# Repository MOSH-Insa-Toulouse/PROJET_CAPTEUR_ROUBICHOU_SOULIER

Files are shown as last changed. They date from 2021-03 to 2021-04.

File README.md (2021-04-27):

# Projet Capteur Graphite ROUBICHOU SOULIER
Bienvenue sur notre Github, découvrez notre travail !

# Sommaire
<!-- TOC depthFrom:2 -->
  - [1. Description](#1-description)
  - [2. Arduino](#2-arduino)
     - [2.1. Bibliothèques](#22-bibliothèques)
     - [2.2. Notre code Arduino](#22-notre-code-arduino)
  - [3. KICAD](#3-kicad)
  - [4. Application Android](#4-application-android)
     - [4.1. MIT App Inventor](#41-mit-app-inventor)
     - [4.2. Installer une application](#42-installer-une-application)
     - [4.3. Notre application](#43-notre-application)
  - [5. Bancs de test](#5-bancs-de-test)
     - [5.1. Première version](#51-première-version)
     - [5.2. Seconde version](#52-seconde-version)
     - [5.3. Résultats](#53-résultats)
  - [6. Améliorations possibles](#6-améliorations-possibles)
  - [7. Informations sur les auteurs](#7-informations-sur-les-auteurs)
<!-- /TOC -->

## 1. Description

Ce Git contient toutes les ressources nécessaires pour le projet capteur 2021 du Génie Physique de l'INSA de Toulouse. Ce projet à pour but le développement d'un **capteur de déformation** à bas coût et écoresponsable. Notre capteur exploite la dépendance entre la conductivité électrique et l’espace moyen entre les particules au sein d’un système granuleux. Le transport des électrons entre les nanoparticules de graphite est régi par l’effet tunnel. Ainsi, l’extension et la contraction du réseau percolé induit par un stress mécanique affectent la distance inter-particule et donc la conductivité électrique globale de la couche de graphite. L’écriture au crayon sur du papier permet la mise en place d’une couche de graphite présentant un réseau percolé. Sa déformation provoque une variation de résistance réversible et exploitable pour créer un extensomètre. Le conditionneur de notre capteur est un Shield comportant un circuit transimpédence ainsi que des interfaces pour un module bluetooth, une roue codeuse et un écran OLED. Ce dernier à été réalisé sur **KICAD**. Le code principal à été réalisé en C++ sur l'**IDE Arduino**. Un application téléphone à été développée sur **MIT App Inventor** pour communiquer et recevoir des données à distance, mais aussi pour contrôler les paramètres du capteur. Un banc de mesure réalisé en **impression 3D** nous permet à l'aide d'un servomoteur d'étudier la réponse en déformation de différents capteurs (dont la concentration en graphite varie).

**Code Arduino**

- Mesure la tension de sortie du circuit transimpédance
- Envoie la mesure de la tension en Bluetooth sur 1 octet
- Calcule la résistance du capteur de graphite connaissant la fonction de transfert du conditionneur
- Affiche les mesures de tension, de résistance et la fréquence d'acquisition choisie sur un écran oled 128x64
- Gère l'encodeur rotatoire pour changer la fréquence d'acquisition

**KICAD**

- PCB sous forme de Shield pour carte Arduino UNO
- Interface du capteur graphite via un circuit transimpédance
- Interface un module Bluetooth
- Interface un écran oled
- Interface un encodeur rotatoire

**Application**

- Récupère la mesure de tension
- Calcule la résistance du capteur de graphite connaissant la fonction de transfert du conditionneur
- Affiche la valeur de la résistance en MΩ
- Trace un graphique qui décrit l'évolution de la mesure de tension au cours du temps
- Mise à l'échelle automatique de l'ordonnée du graphique
- Possibilité de changer la fréquence d'acquisition (100 ou 20 Hz)
- Possibilité de mettre sur ON ou OFF l'application en temps réel

**Banc de test**

- Fonctionne avec un servomoteur
- Permet de générer des contraintes avec des consignes d'angles
- Permet une grande plage de contraintes
- Améliore la répétabilité des mesures
- Permet la mise en place de mesures autonomes
- Limite la déterioration des capteurs de graphite

## 2. Arduino

_Comment installer l'IDE Arduino sur sa machine? Vous trouverez la réponse [ici](https://www.arduino.cc/en/software)_

### 2.1 Bibliothèques

- Installez la bibliothèque "Adafruit GFX Library" [ici](https://github.com/adafruit/Adafruit-GFX-Library)
- Installez la bibliothèque "Adafruit SSD1306" [ici](https://github.com/adafruit/Adafruit_SSD1306)
- Installez la bibliothèque "Adafruit BusIOa" [ici](https://github.com/adafruit/Adafruit_BusIO)

_Comment installer une bibliothèque Arduino? Vous trouverez la réponse [ici](https://www.arduino.cc/en/Guide/Libraries#how-to-install-a-library)_

### 2.2. Notre code Arduino

Le code que nous avons développé permet de:
- Mesurer la tension de sortie du circuit transimpédance
- Envoyer la mesure de la tension en Bluetooth sur 1 octet
- Calculer la résistance du capteur de graphite connaissant la fonction de transfert du conditionneur
- Afficher les mesures de tension, de résistance et la fréquence d'acquisition choisie sur un écran oled 128x64
- Gèrer l'encodeur rotatoire pour changer la fréquence d'acquisition

**Notre code Arduino est à télécharger [ici](https://github.com/MOSH-Insa-Toulouse/PROJET_CAPTEUR_ROUBICHOU_SOULIER/blob/230c8323b89008d6615a6afa0b6356e3ce4d4a17/Code%20Arduino/Projet_Capteur.ino)** 

``` c++
#include <SoftwareSerial.h>
#include <Arduino.h>
#include <SPI.h>
#include <Wire.h>
#include <Adafruit_GFX.h>
#include <Adafruit_SSD1306.h>
double sensorValue;
double sensorVolt;

/////////////////OLED//////////////////////////////////////
#define OLED_RESET 4
Adafruit_SSD1306 display(-1);

#define NUMFLAKES 10
#define XPOS 0
#define YPOS 1
#define DELTAY 2
#define LOGO16_GLCD_HEIGHT 32
#define LOGO16_GLCD_WIDTH  128 

///////////////////Bluetooth////////////////////////////////
#define rxPin 10
#define txPin 11
#define baudrate 9600
#define pin A0
int etat;
SoftwareSerial mySerial(rxPin,txPin);
String c = "b";

//////////////////////ROUE//////////////////////////////////
#define encoder0pinA 2
#define encoder0pinB 4
#define Switch 5
volatile unsigned int freq = 50;

/////////////////////FCT ECRAN/////////////////////////////
void OLED(String text, int x, int y,int size, boolean d) 
{
  display.setTextSize(size);
  display.setTextColor(WHITE);
  display.setCursor(x,y);
  display.println(text);
  
  if(d)
  {
    display.display();
  }
  //delay(100);
}

////////////////////FCT ROUE//////////////////////////////
void doEncoder()
{
  if(digitalRead(encoder0pinB)==HIGH){
    freq=10;
  }
  else
  {
    freq=50;
  }
}

void setup() 
{
///////////////Bluetooth////////////////////////////////
Serial.begin(baudrate);
pinMode(rxPin,INPUT);
pinMode(txPin,OUTPUT);
  
pinMode(pin,INPUT);
mySerial.begin(baudrate); //bluetooth

///////////////OLED/////////////////////////////////////
display.begin(SSD1306_SWITCHCAPVCC, 0x3C);//Inititalisation de l'écran
display.display();
delay(2000);
display.clearDisplay(); 

//////////////ROUE/////////////////////////////////////
pinMode(encoder0pinA,INPUT);
digitalWrite(encoder0pinA,HIGH);
pinMode(encoder0pinB,INPUT);
digitalWrite(encoder0pinB,HIGH);
attachInterrupt(0,doEncoder, RISING);//intéruption lors du mouvement de la roue
}

void loop()
{ 
/////////////////CAPTEUR//////////////////////////////  
byte val=map(analogRead(pin),0,1024,0,127);

float f=1/(freq*0.001);

int R1= 100000;
int R2 = 1000;
int R3 = 100000;
int R5 = 10000;

sensorVolt = analogRead(pin)*0.004882814; //valeur en Volt
sensorValue = (1+R3/R2)*R1*(5/sensorVolt)-R1-R5;//valeur en Mohm
//Serial.println(sensorValue);
String vString = String(sensorVolt, 2); //transforme la donnée des volt en string
String RString =  String(sensorValue, 0); //transforme la donnée de résistance en string
String fString = String(f, 3); //transforme la donnée de la fréquence en string

///////////////BLUETOOTH////////////////////////////////
if(mySerial.available()>0){
char data = mySerial.read();
String DataStr = String(data);
DataStr.trim();
Serial.println(DataStr);

if (c=!DataStr)
{
  c=DataStr;
  }

if (DataStr=="a")         ///
  {                       ///
  etat = 1;               ///
  }                       /// Mise à "ON" ou "OFF" de l'envoi des données par l'apk
else if (DataStr=="b")    ///
  {                       ///
   etat = 0;              ///
  }
else if (DataStr=="c")    ///
  {                       ///
  freq=10;                ///
  }                       ///
else if (DataStr=="d")    /// Choix de fréquence depuis l'apk
  {                       ///
  freq=50;                ///
  }                       ///
}

switch(etat)
{
  case 0:
  break;

  case 1:
  mySerial.write(val);     ///envoie la donnée à l'application
  Serial.print(val);
  break;
  }

///////////////////OLED/////////////////////////////
display.clearDisplay();
 
OLED("Res(Mohm):          ", 20, 3, 1.9, false);
OLED(RString, 90, 3, 1, false); ///Ecriture de la resistance sur l'OLED
OLED("", 110, 3, 1, false);

OLED("Volt :     ", 20, 12, 1.9, false);
OLED(vString, 80, 12, 1, false); ///Ecriture de la tension sur l'OLED
OLED("V", 110, 12, 1, false);

OLED("Freq:          ", 20, 21, 1.9, false);
OLED(fString, 72, 21, 1.9, false);  ///Ecriture de la fréquence sur l'OLED
OLED("Hz", 110, 21, 1.9, false);

display.drawRect(1, 1, 126,31, WHITE); ///Met le rectangle autour de l'oled
display.display();

delay(freq); ///Règle la fréquence d'aquisition et d'envoi
}
```

## 3. KICAD

_Comment installer KICAD sur sa machine? La réponse se trouve [ici](https://www.kicad.org/)_

Vous trouverez ci-dessous un aperçu de l'empreinte du Shield que nous avons développé. Le projet sur le logiciel KICAD permet de:

- Créer PCB sous forme de Shield pour carte Arduino UNO
- Interfacer le capteur au graphite via un circuit transimpédance
- Interfacer un module Bluetooth
- Interfacer un écran oled
- Interfacer un encodeur rotatoire

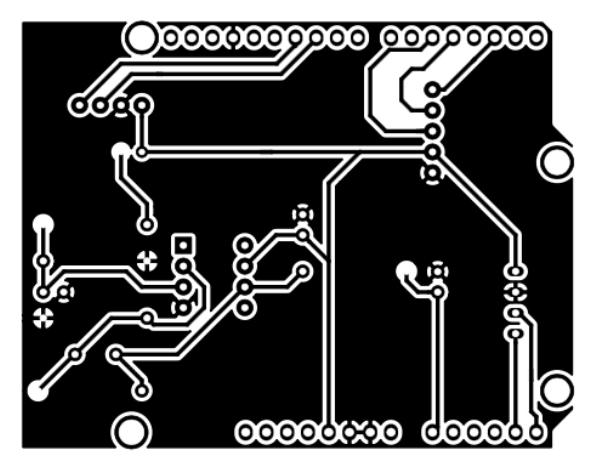
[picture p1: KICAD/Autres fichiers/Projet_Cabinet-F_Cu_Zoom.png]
Projet_Cabinet-F_Cu_Zoom


**L'empreinte au format PDF est à télécharger [ici](https://github.com/MOSH-Insa-Toulouse/PROJET_CAPTEUR_ROUBICHOU_SOULIER/tree/main/KICAD/PDF)**

**L'empreinte au format GERBER est à télécharger [ici](https://github.com/MOSH-Insa-Toulouse/PROJET_CAPTEUR_ROUBICHOU_SOULIER/tree/main/KICAD/GERBER)**

**Notre projet KICAD est à télécharger [ici](https://github.com/MOSH-Insa-Toulouse/PROJET_CAPTEUR_ROUBICHOU_SOULIER/tree/main/KICAD/Projet%20KICAD)**

Ci-dessous est l’application typique du capteur dans un circuit analogique. La résistance R5 protège l’amplificateur opérationnel des décharges électrostatiques et forme avec la capacité C1 un filtre pour les bruits en tension. La capacité C1 et la résistance R1 forment un filtre pour le bruit en courant. La résistance R2 est interchangeable pour pouvoir adapter le calibre. La capacité C4 avec la résistance R3 forment un filtre actif, tandis que C2 et R6 forment le filtre de sortie. La capacité C3 permet de filtrer le bruit sur l’alimentation. Le signal délivré par le capteur traverse un pont diviseur de tension. La tension résultante en sortie est amplifiée par l’amplificateur opérationnel LTC1050 puis elle est filtrée par un filtre RC de sortie. La tension associée à l’étiquette ADC peut être connectée à un ADC 5V. Une carte Arduino peut être utilisée à cet effet.

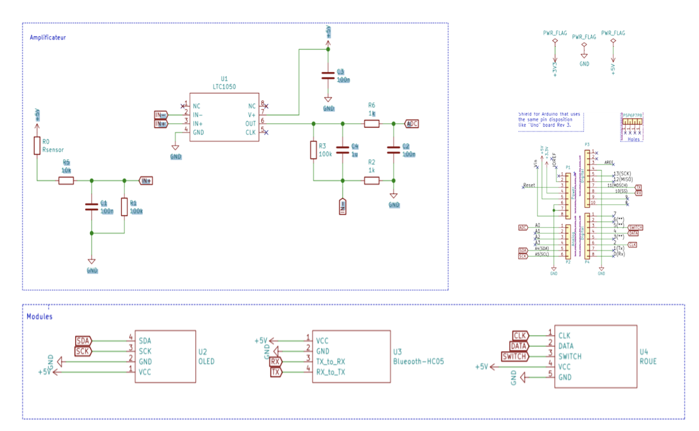
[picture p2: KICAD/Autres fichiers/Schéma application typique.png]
Schema_application_typique


## 4. Application Android

### 4.1. MIT App Inventor

_Le site internet de création d'application MIT App Inventor est accessible en cliquant [ici](https://appinventor.mit.edu)_

### 4.2. Installer une application

_Comment installer un fichier .apk à partir d'un PC? La réponse se trouve [ici](https://fr.wikihow.com/installer-sur-un-Android-des-fichiers-APK-%C3%A0-partir-d%E2%80%99un-PC)_

### 4.3. Notre application

Vous trouverez ci-dessous un aperçu de l'application que nous avons développé. Cette application permet de:
- Récupérer la mesure de tension
- Calculer la résistance du capteur de graphite connaissant la fonction de transfert du conditionneur
- Afficher la valeur de la résistance en MΩ
- Tracer un graphique qui décrit l'évolution de la mesure de tension au cours du temps
- Mettre à l'échelle automatique de l'ordonnée du graphique
- Changer la fréquence d'acquisition (100 ou 20 Hz)
- Mettre sur ON ou OFF l'application en temps réel

**Le code de notre application (.aia) est à télécharger [ici](https://github.com/MOSH-Insa-Toulouse/PROJET_CAPTEUR_ROUBICHOU_SOULIER/blob/26b40920e06c2dba8526cb9ba54827a0fe55c7c3/Application/ShieldcinqA_II.aia)**

**Le code de notre application (.apk) est à télécharger [ici](https://github.com/MOSH-Insa-Toulouse/PROJET_CAPTEUR_ROUBICHOU_SOULIER/blob/f0df43999fbf93bf9aa83195ed25307b022c2bd4/Application/ShieldcinqA_II.apk)**

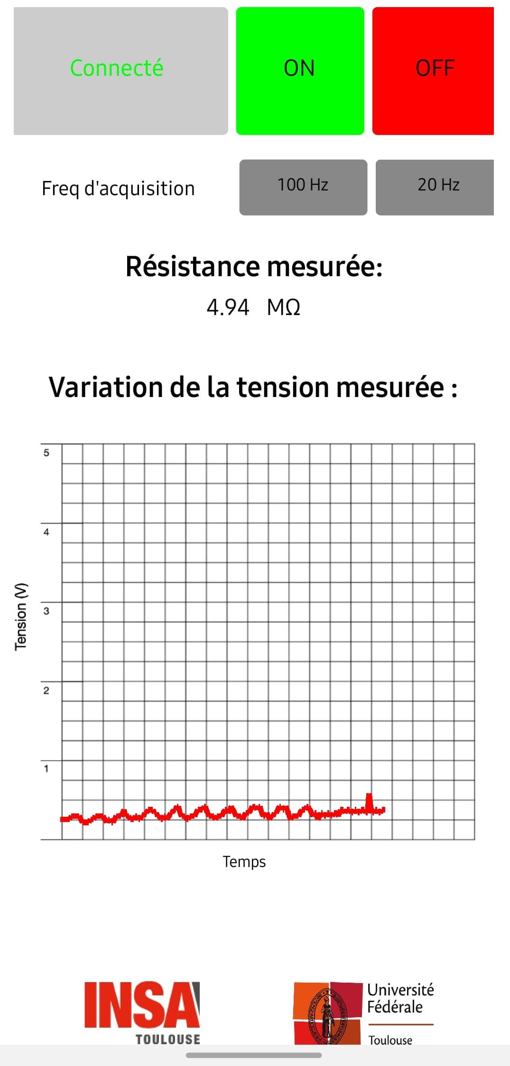
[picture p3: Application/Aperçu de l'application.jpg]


## 5. Bancs de test

### 5.1. Première version 

Notre première version du banc de test était une tour composée des cylindres de différents diamètres connus. Cette tour permet l'application de plusieurs contraintes à notre capteur. Cependant, ce banc conduisait à des déformations irréversibles de notre capteur. Aussi, ce banc n'était pas autonome et la reproductibilité n'était pas optimale.

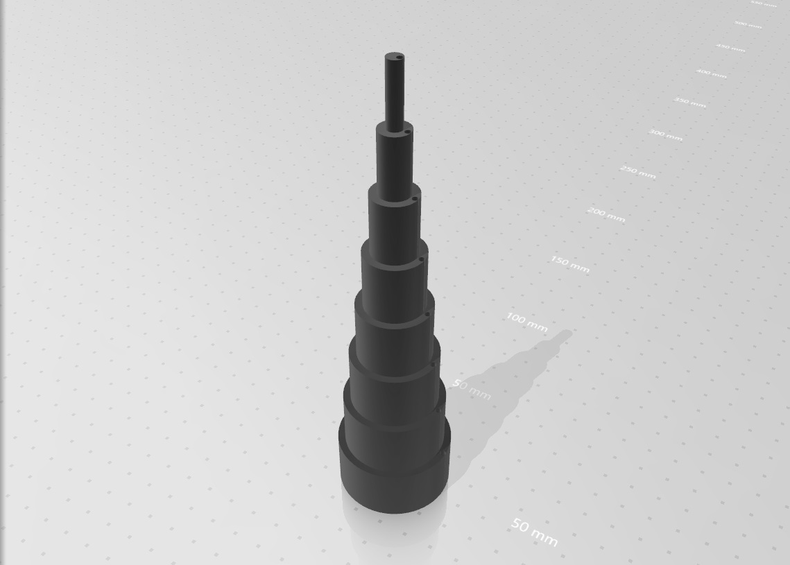
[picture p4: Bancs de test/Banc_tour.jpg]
Banc_tour


### 5.2. Seconde version 

Nous sommes donc passés à un banc de test fonctionnant avec un servomoteur. Ce dernier système permet de générer des contraintes avec des consignes d'angles et autorise, de ce fait, une grande plage de contraintes. Finalement ce banc de test est optimal car il permet la mise en place de mesures autonomes, améliore la répétabilité des mesures et limite la déterioration des capteurs de graphite.

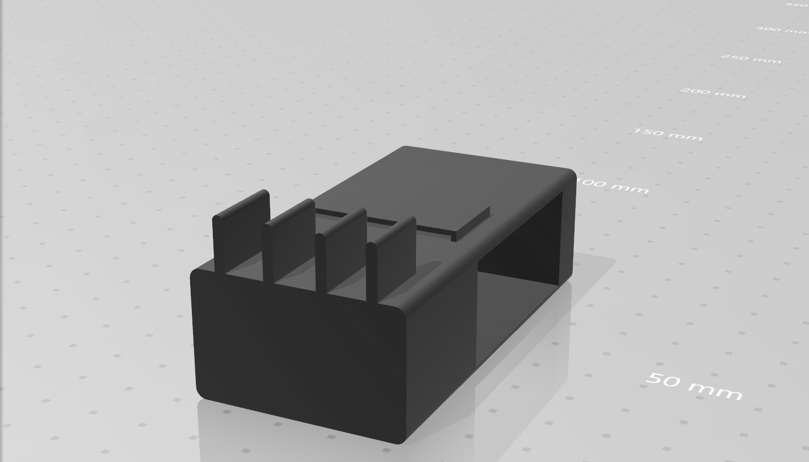
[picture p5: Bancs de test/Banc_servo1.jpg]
Banc_servo1


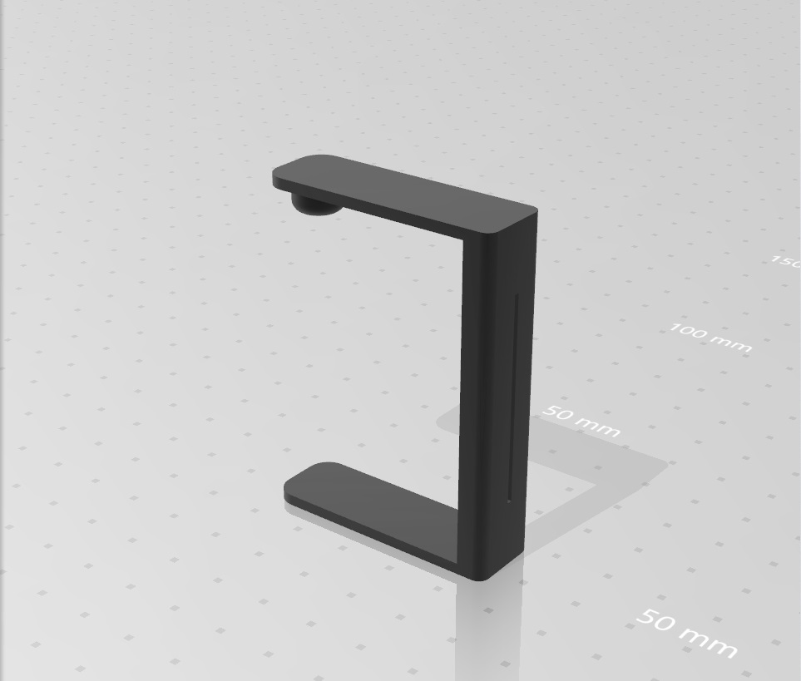
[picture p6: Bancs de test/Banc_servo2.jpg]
Banc_servo2


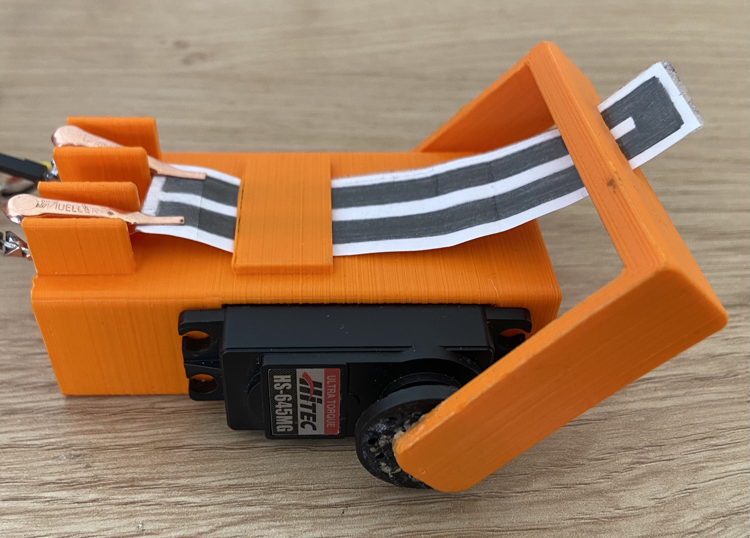
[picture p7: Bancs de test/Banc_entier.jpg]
Banc_entier


**Les fichiers STL que nous avons créés sont à télécharger au ci-dessous:**

- Banc sous forme de tour [ici](https://github.com/MOSH-Insa-Toulouse/PROJET_CAPTEUR_ROUBICHOU_SOULIER/blob/9662f01d69eacdf1dfc96737585869e709ca6d86/Bancs%20de%20test/PieceCapteur3%20v1.stl)
- Banc avec servomoteur (pièce 1) [ici](https://github.com/MOSH-Insa-Toulouse/PROJET_CAPTEUR_ROUBICHOU_SOULIER/blob/e755654e5a37c8409d6181bdfd030661f82570d9/Bancs%20de%20test/Banc1%20v3.stl)
- Banc avec servomoteur (pièce 2)[ici](https://github.com/MOSH-Insa-Toulouse/PROJET_CAPTEUR_ROUBICHOU_SOULIER/blob/b976cd1678c3cf63028d5a895135fa7c54baf83e/Bancs%20de%20test/Banc2%20v1.stl)

### 5.3. Résultats

Les caractéristiques du capteur ont été déterminées par la mesure de la résistance pour différentes déformations appliquées. L’expérience a été réalisée pour différents types de crayons (2H, HB et B) dont la concentration en graphite varie.

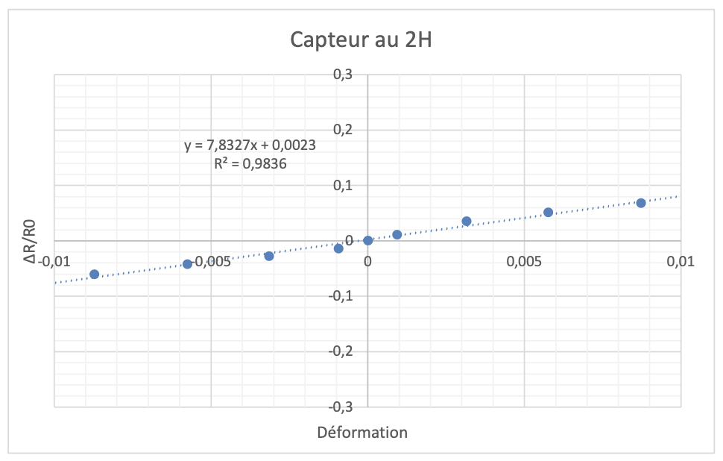
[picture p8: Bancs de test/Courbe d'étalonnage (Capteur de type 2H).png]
Capteur 2H


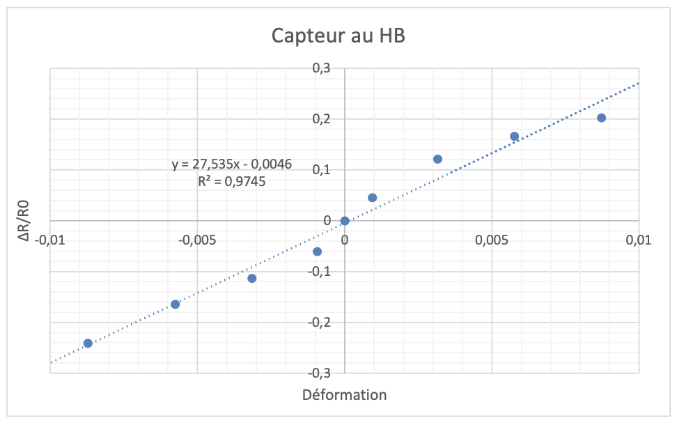
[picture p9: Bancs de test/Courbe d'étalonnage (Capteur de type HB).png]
Capteur HB


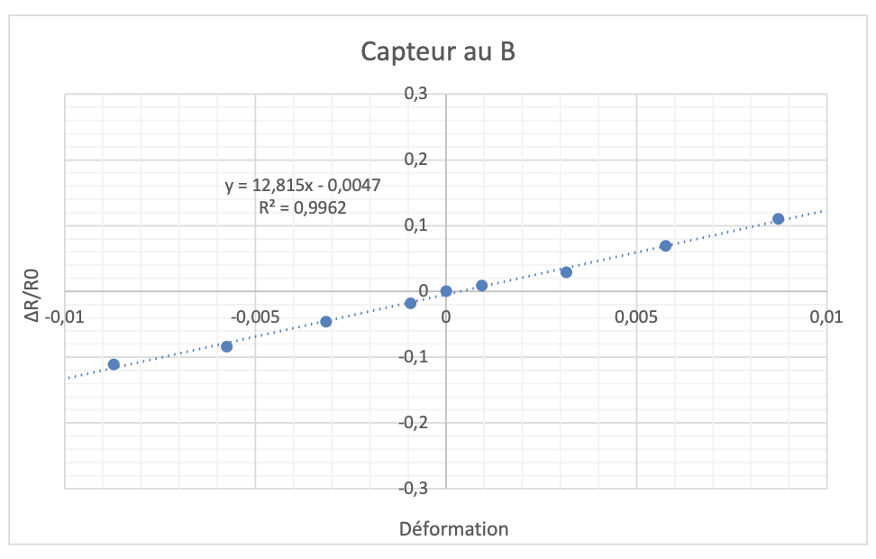
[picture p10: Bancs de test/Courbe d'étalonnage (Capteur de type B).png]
Capteur 2B


## 6. Améliorations possibles

- Améliorer la banc de test pour qu'il puisse faire des contrainte en extension et en contraction sur le capteur sans le retourner.
- Optimiser le type de capteur, notamment en améliroant la qualité du papier utiliser ou la façon de plastifier le capteur.
- Adapter le circuit électronique à un type de capteur pour en optimiser les performances.

## 7. Informations sur les auteurs

**Jordi ROUBICHOU & Mathias SOULIER**

- Étudiants en 4 ième année du Génie Physique de l'INSA de Toulouse

- _roubicho@etud.insa-toulouse.fr_

- _msoulier@etud.insa-toulouse.fr_

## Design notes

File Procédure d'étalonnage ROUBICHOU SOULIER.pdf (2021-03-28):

ROUBICHOU, SOULIER

## Procédure d’étalonnage de la chaîne de mesure

### Capteur et banc de test:

Notre capteur est composé d’une carte Arduino Uno et d’un Shield que nous avons développé. Ce Shield permet de filtrer et d’amplifier le signal mesuré par le capteur. Il permet aussi l’interfaçage entre différents modules dont un écran OLED, un module Bluetooth, une roue codeuse et le capteur.

(1) OLED : Affiche en direct la mesure en Volts ou en Ohm
(2) HC-05 : module Bluetooth pour communiquer avec le téléphone
(3) Roue codeuse : Elément de réglage de l’affichage sur l’oled
(4) Capteur
(5) USB : Liaison vers le PC
(6) Banc de test

Notre capteur exploite la dépendance entre la conductivité électrique et l’espace moyen entre les particules au sein d’un système granuleux. Le transport des électrons entre les nanoparticules de graphite est régi par l’effet tunnel. Ainsi, l’extension et la contraction du réseau percolé induit par un stress mécanique affectent la distance inter-particule et donc la conductivité électrique globale de la couche de graphite. L’écriture au crayon sur du papier permet la mise en place d’une couche de graphite présentant un réseau percolé. Sa déformation provoque une variation de résistance réversible et exploitable pour créer un extensomètre.

Pour tenter d’étudier le potentiel de ce capteur de déformation, nous avons développé deux bancs de tests. Notre première version du banc de test était une tour composée des cylindres de différents diamètres connus. Cette tour permettait l'application de plusieurs contraintes en extension et en contraction à notre capteur. Cependant, ce banc conduisait à des déformations irréversibles de notre capteur. Aussi, ce banc n'était pas autonome et la reproductibilité n'était pas optimale. Nous sommes donc passés à un banc de test fonctionnant avec un servomoteur. Ce dernier système permet de générer des contraintes avec des consignes d'angles et autorise, de ce fait, une grande plage de contraintes. Finalement ce banc de test est optimal car il permet la mise en place de mesures autonomes, améliore la répétabilité des mesures et limite la détérioration des capteurs de graphite.

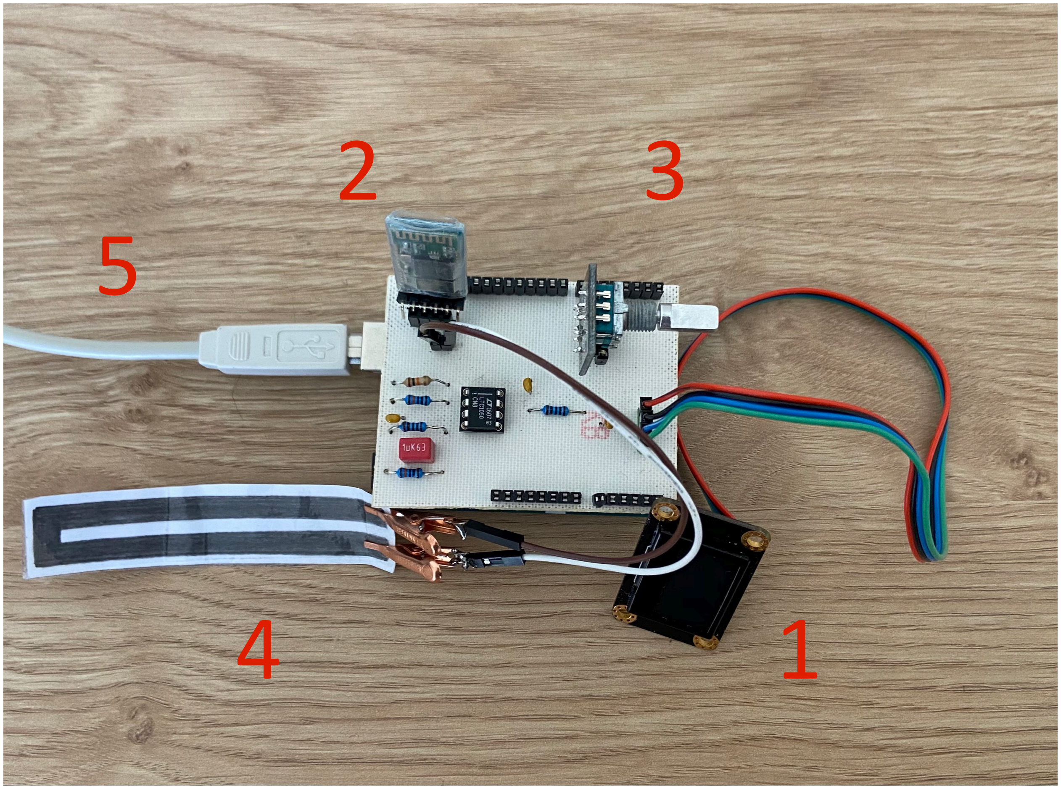
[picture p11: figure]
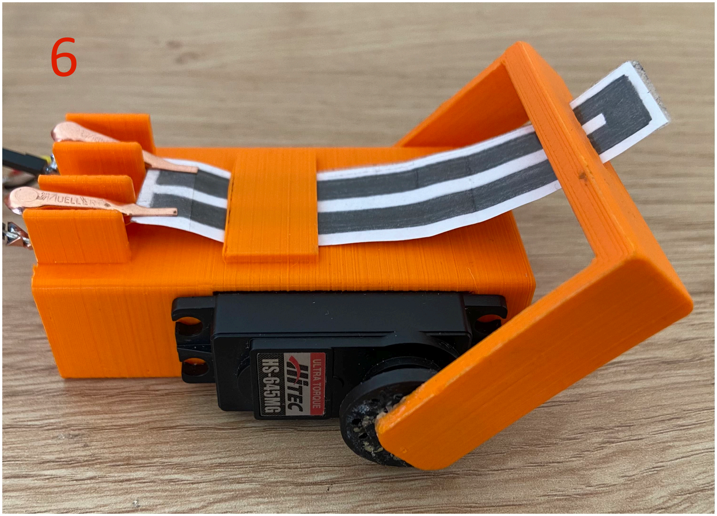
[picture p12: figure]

ROUBICHOU, SOULIER

### Procédure d’étalonnage en traction :

1: On place les pinces crocodile dédiées sur les électrodes du capteur sans l’introduire sur notre banc

2: On améliore le capteur de sorte à ce que le signal mesuré soit supérieur à 1V. Si ce n’est pas le cas on rajoute du graphite sur le capteur à l’aide d’un crayon à papier. Une fois le capteur optimal, on enlève les électrodes

3: On insère le capteur sur notre banc en le faisant passer par les fentes dédiées

4: On place de nouveau les pinces crocodile en les insérant dans la partie dédiée sur le banc pour ne pas qu’elles ne rentrent en contact.

5: On mesure la valeur de référence R0 de notre capteur lorsque le capteur est horizontal.

6: On lance le programme qui permet l’application de plusieurs consignes d’angles par le servomoteur. Nous relevons alors la valeur de résistance pour les différents angles.

### Lien entre la déformation et les variations d’angle du banc de mesure:

Le plus difficile dans notre banc expérimental est le fait que nous ne connaissons pas le rayon de courbure associé aux consignes d’angles que nous appliquons. Nous pouvons cependant remonter au rayon de courbure associé à une consigne d’angle par la mesure de la flèche F et la distance A entre le point le plus bas et le plus haut de notre capteur. De plus, si nous connaissons l’épaisseur du capteur de papier (0,3mm) et le rayon de courbure, nous pouvons calculer la déformation de notre capteur. Finalement, nous pouvons tracer une courbe d’étalonnage telle que : ∆R/R0=f(ε) (voir la Datasheet).

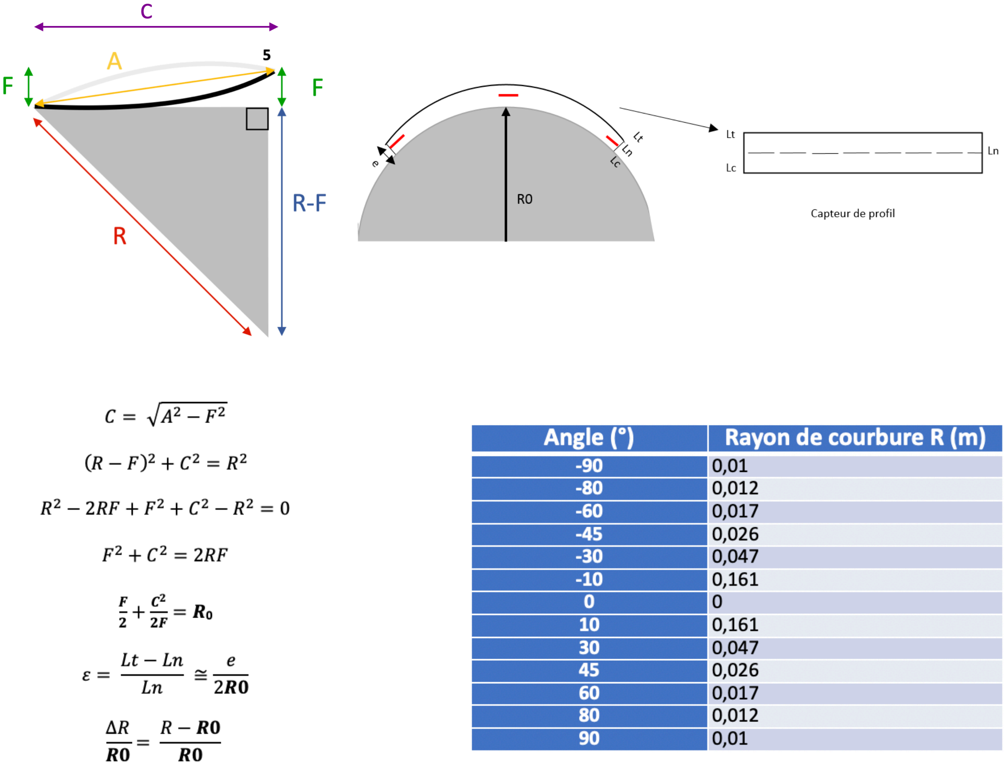
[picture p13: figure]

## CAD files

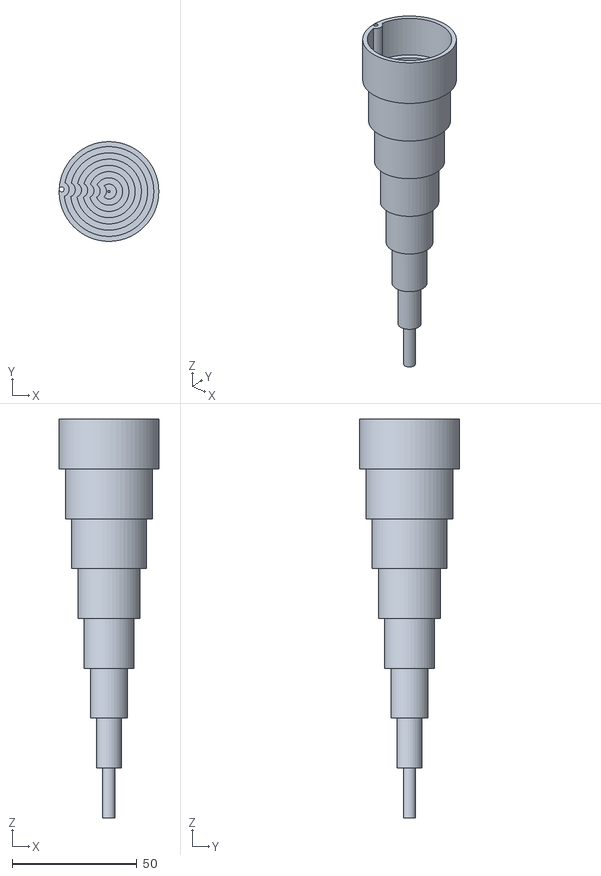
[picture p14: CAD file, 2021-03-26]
Bancs de test/PieceCapteur3 v1.stl
40.0 x 40.0 x 160.0

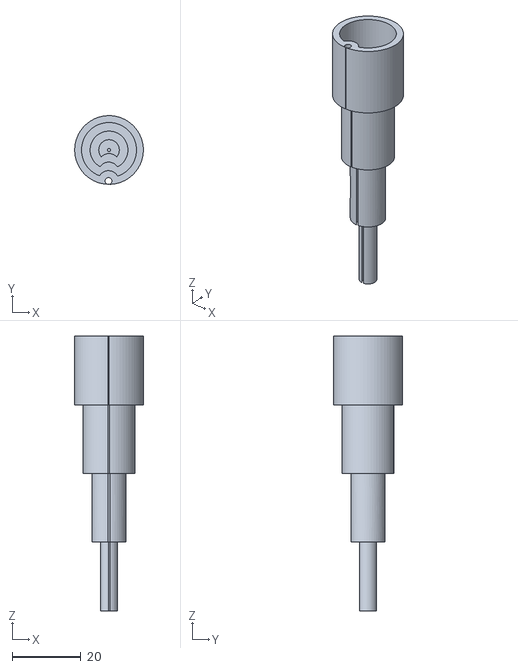
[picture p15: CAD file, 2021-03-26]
Bancs de test/CapteurPiece1 v2.stl
20.0 x 20.0 x 80.0

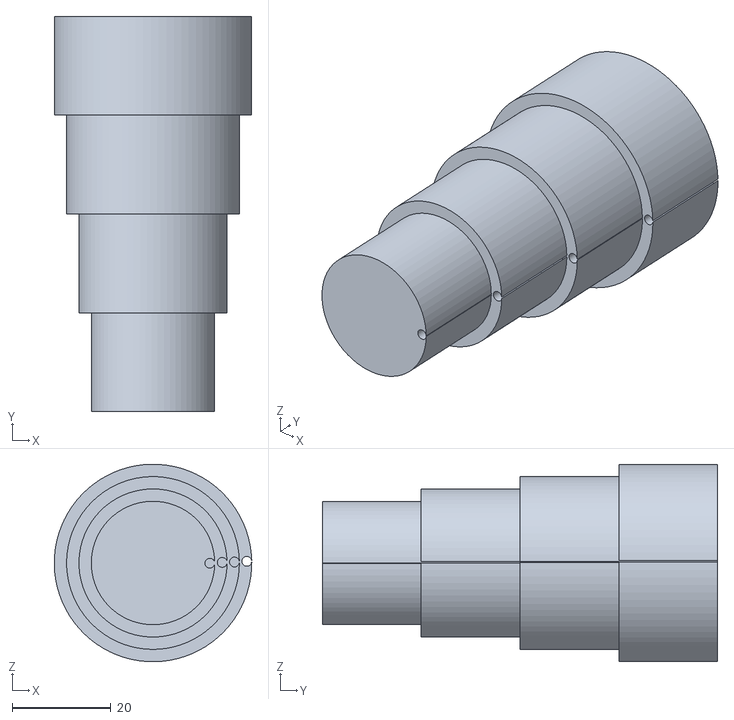
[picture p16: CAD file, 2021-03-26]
Bancs de test/CapteurPiece2 v2.stl
40.0 x 80.0 x 40.0

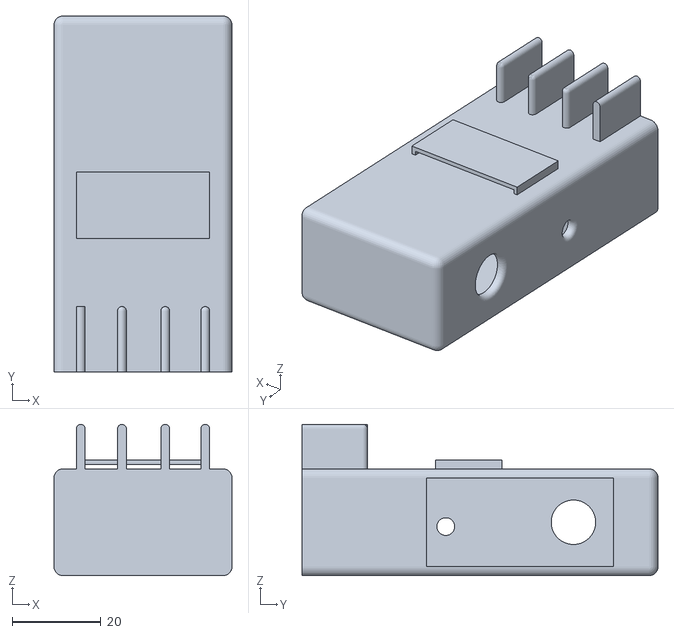
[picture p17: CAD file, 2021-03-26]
Bancs de test/Banc1 v3.stl
40.0 x 80.0 x 34.0

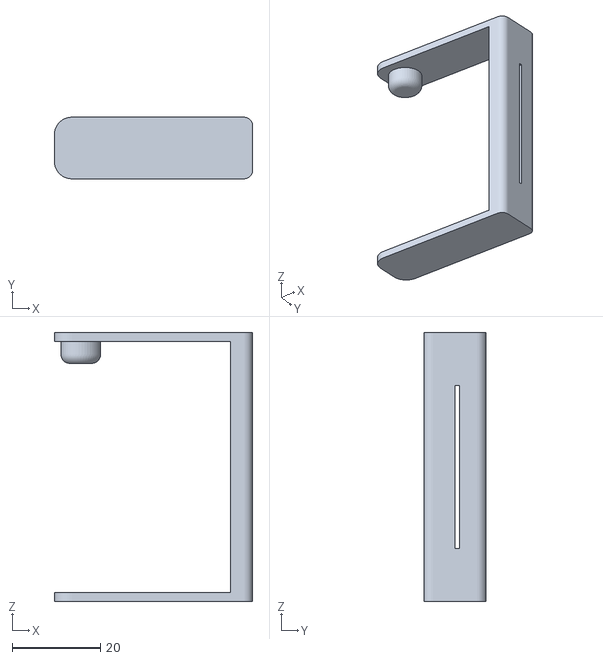
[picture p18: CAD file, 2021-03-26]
Bancs de test/Banc2 v1.stl
45.0 x 14.0 x 61.0

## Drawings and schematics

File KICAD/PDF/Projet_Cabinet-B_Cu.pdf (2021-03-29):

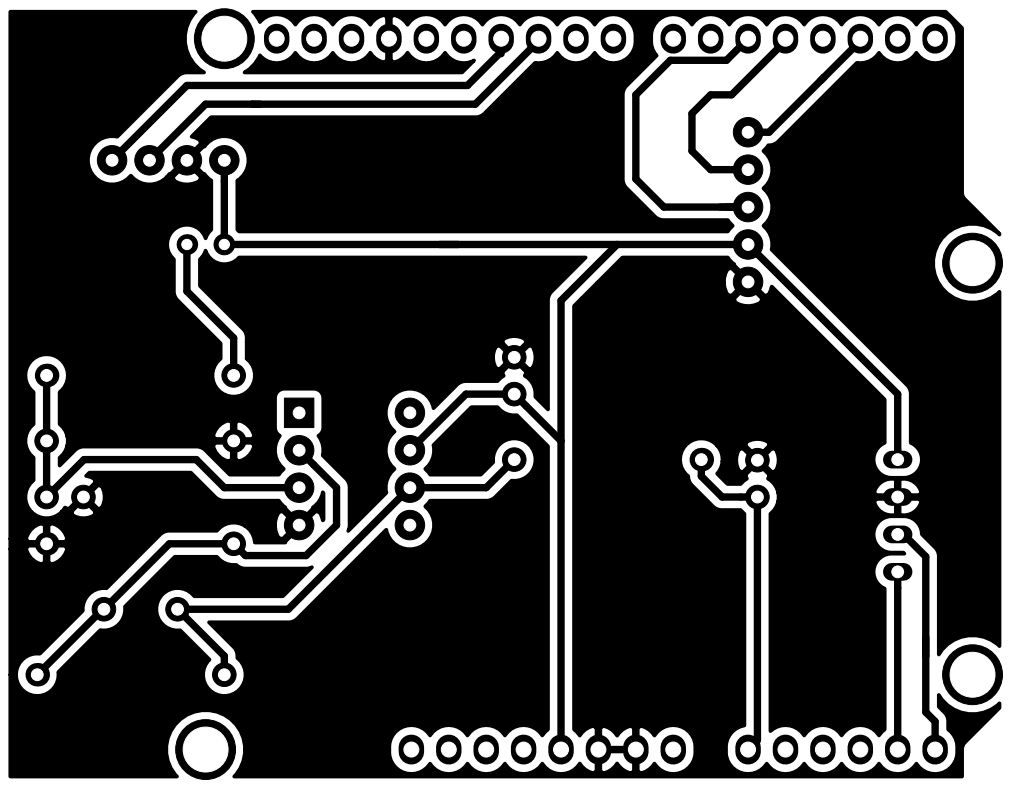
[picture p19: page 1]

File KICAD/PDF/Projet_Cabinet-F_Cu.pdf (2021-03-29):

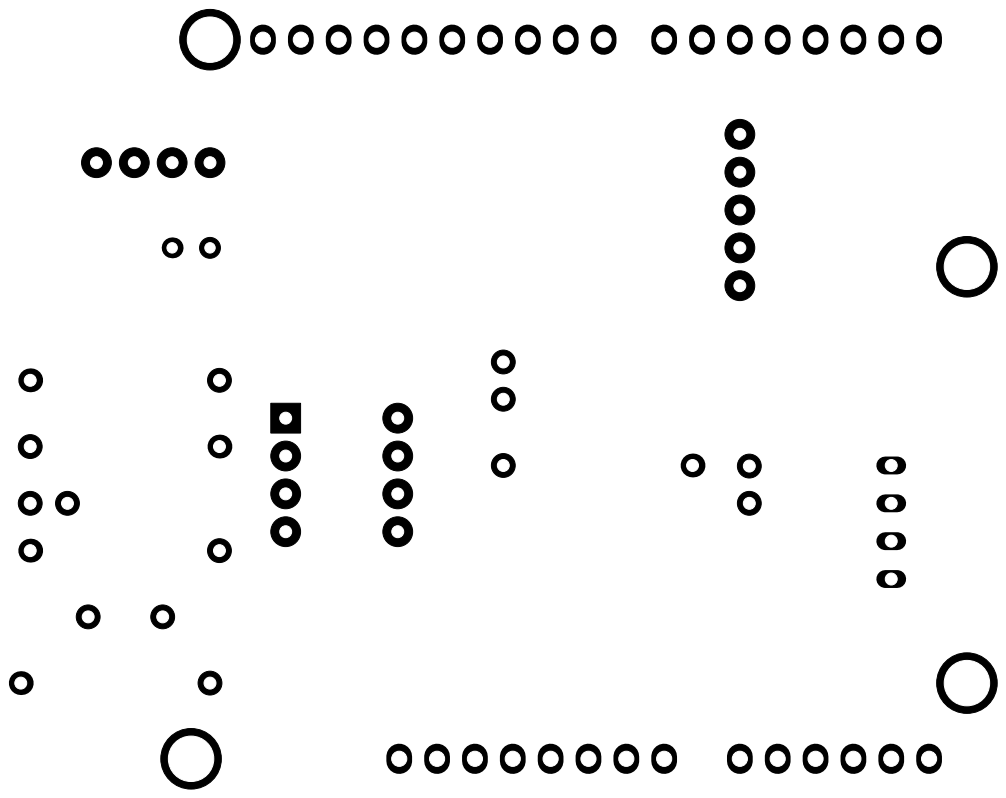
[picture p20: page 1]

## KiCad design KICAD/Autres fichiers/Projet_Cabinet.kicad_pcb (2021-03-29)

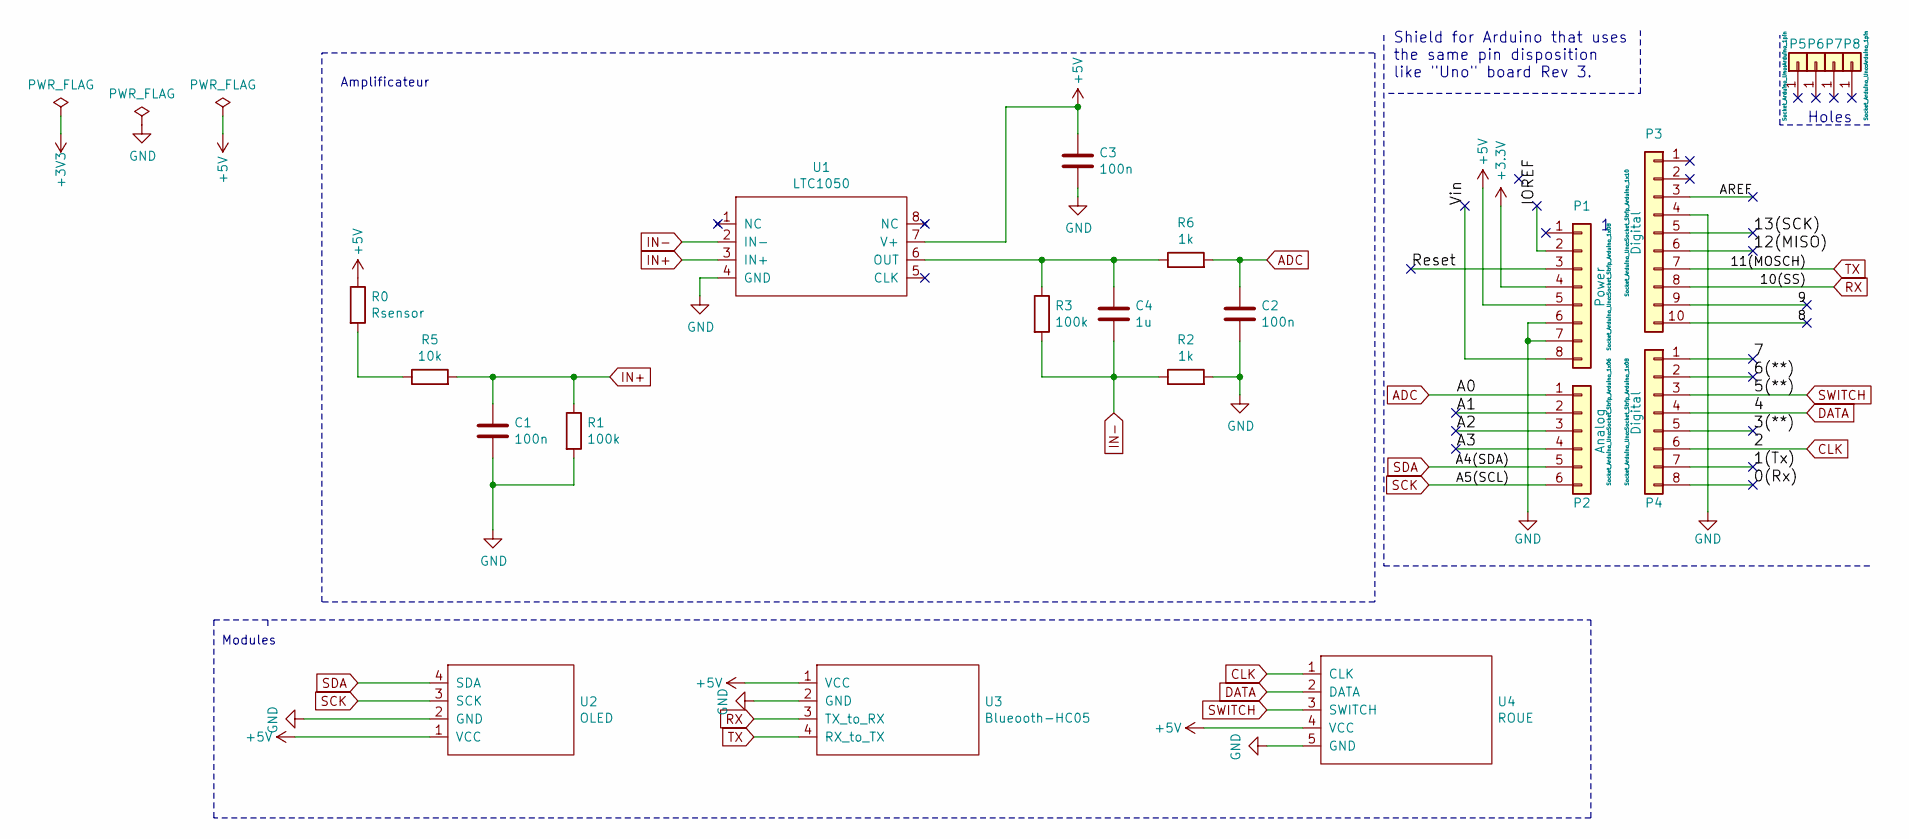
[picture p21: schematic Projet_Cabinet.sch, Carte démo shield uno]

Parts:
C1, C2, C3: 100n; C_Disc_D3.0mm_W1.6mm_P2.50mm
C4: 1u; C_Rect_L7.0mm_W3.5mm_P5.00mm
P1: Power; Socket_Strip_Arduino_1x08
P2: Analog; Socket_Strip_Arduino_1x06
P3: Digital; Socket_Strip_Arduino_1x10
P4: Digital; Socket_Strip_Arduino_1x08
P5, P6, P7, P8: CONN_01X01; Arduino_1pin
R0: Rsensor; R_Axial_DIN0204_L3.6mm_D1.6mm_P2.54mm_Vertical
R1, R3: 100k; R_Axial_DIN0309_L9.0mm_D3.2mm_P12.70mm_Horizontal
R2, R6: 1k; R_Axial_DIN0309_L9.0mm_D3.2mm_P12.70mm_Horizontal
R5: 10k; R_Axial_DIN0309_L9.0mm_D3.2mm_P12.70mm_Horizontal
U1: LTC1050
U2: OLED
U3: Blueooth-HC05; HC05
U4: ROUE; Roue

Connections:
+3V3: P1.4
+5V: C3.1, P1.5, R0.1, U1.7 (V+), U2.1 (VCC), U3.1 (VCC), U4.4 (VCC)
/0(Rx): P4.8
/1(Tx): P4.7
/3(**): P4.5
/6(**): P4.2
/7: P4.1
/8: P3.10
/9: P3.9
/12(MISO): P3.6
/13(SCK): P3.5
/A1: P2.2
/A2: P2.3
/A3: P2.4
/AREF: P3.3
/IOREF: P1.2
/Reset: P1.3
/Vin: P1.8
ADC: C2.1, P2.1, R6.2
CLK: P4.6, U4.1 (CLK)
DATA: P4.4, U4.2 (DATA)
GND: C1.2, C2.2, C3.2, P1.6, P1.7, P3.4, R1.2, R2.2, U1.4 (GND), U2.2 (GND), U3.2 (GND), U4.5 (GND)
IN+: C1.1, R1.1, R5.2, U1.3 (IN+)
IN-: C4.2, R2.1, R3.2, U1.2 (IN-)
unnamed: C4.1, R3.1, R6.1, U1.6 (OUT)
unnamed: R0.2, R5.1
RX: P3.8, U3.3 (TX_to_RX)
SCK: P2.6, U2.3 (SCK)
SDA: P2.5, U2.4 (SDA)
SWITCH: P4.3, U4.3 (SWITCH)
TX: P3.7, U3.4 (RX_to_TX)

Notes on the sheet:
Holes
Shield for Arduino that uses the same pin disposition like "Uno" board Rev 3.
Amplificateur
Modules

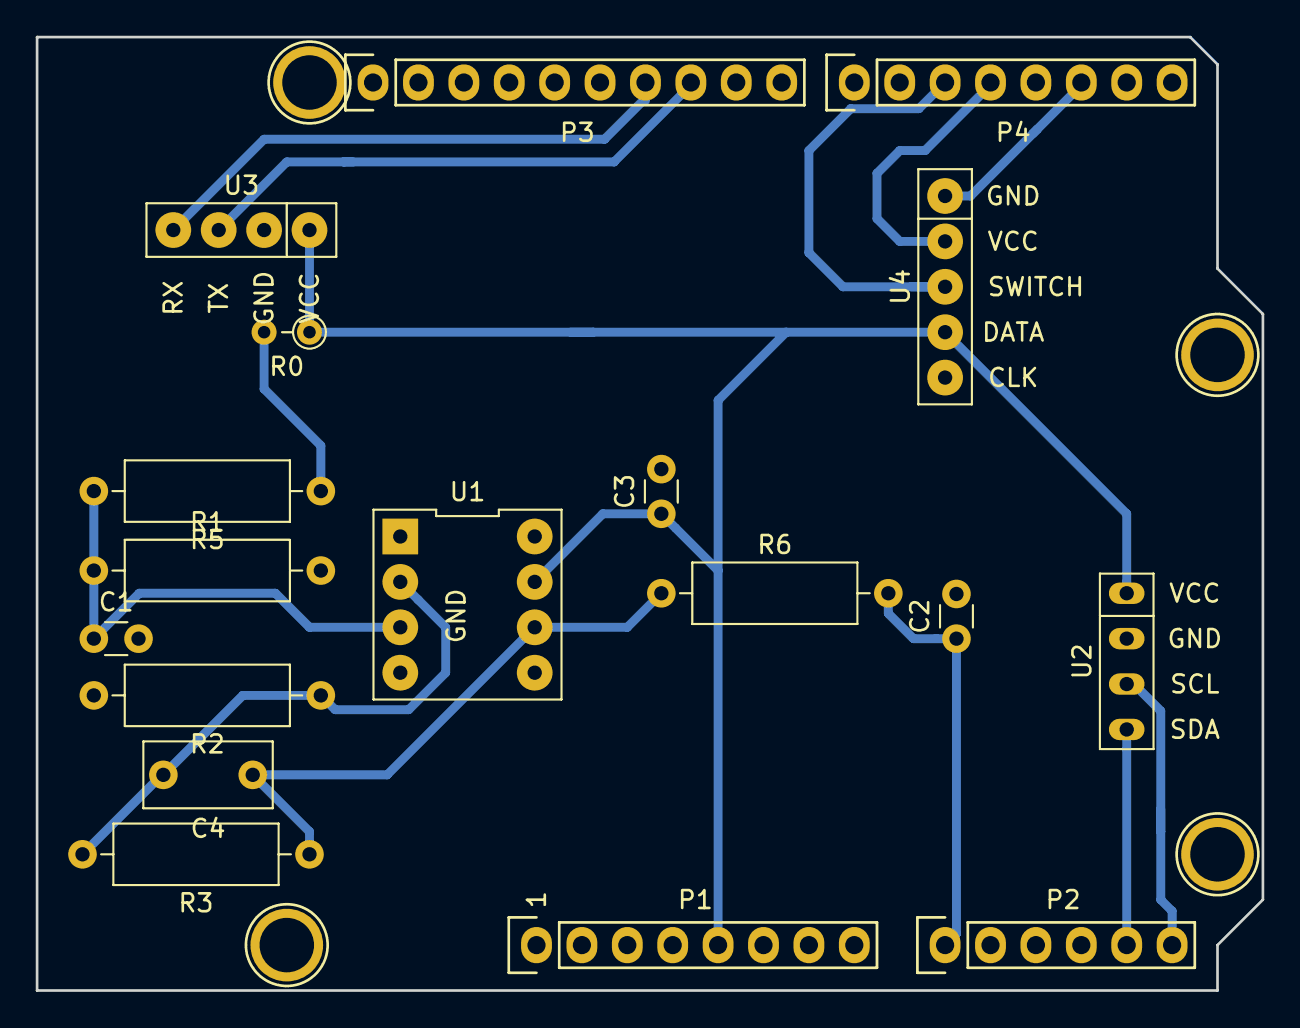
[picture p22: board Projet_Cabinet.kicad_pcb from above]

Board: 2 copper layers, 68.6 x 53.3 mm, 22 parts (0 on the bottom side), 14 nets.
